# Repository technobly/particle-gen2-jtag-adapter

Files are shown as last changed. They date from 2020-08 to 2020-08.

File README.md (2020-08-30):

Particle Gen2 JTAG/SWD adapter for Gen3 Debugger
===

Allows you to easily connect a Gen3 Particle Debugger to a Gen2 Photon/Electron in circuit using pass-through headers.

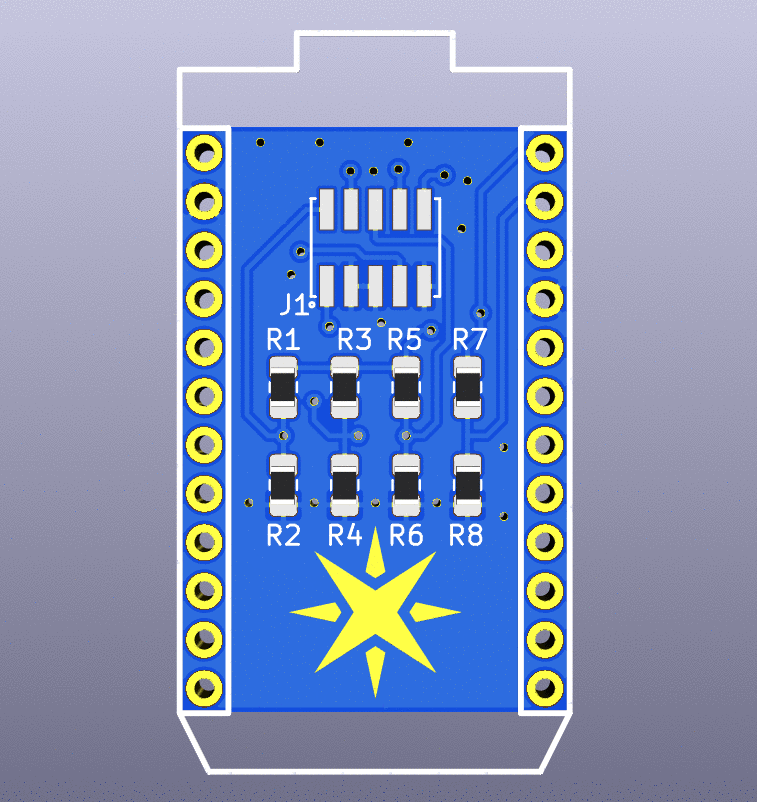
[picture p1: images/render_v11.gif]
render

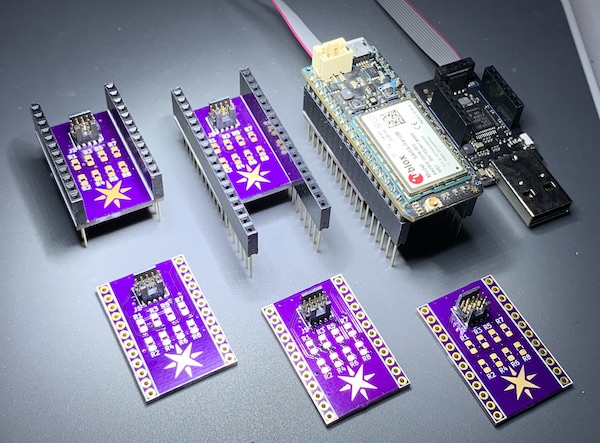
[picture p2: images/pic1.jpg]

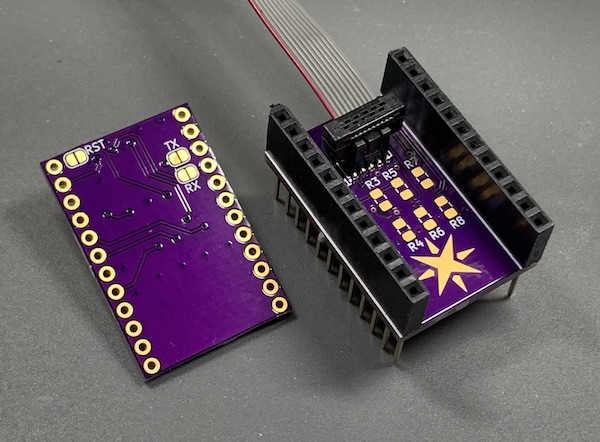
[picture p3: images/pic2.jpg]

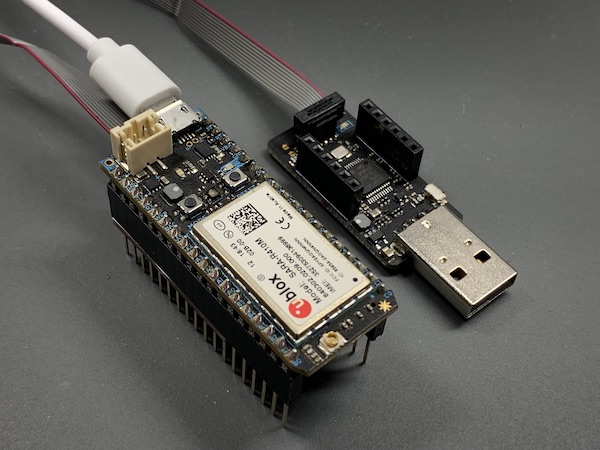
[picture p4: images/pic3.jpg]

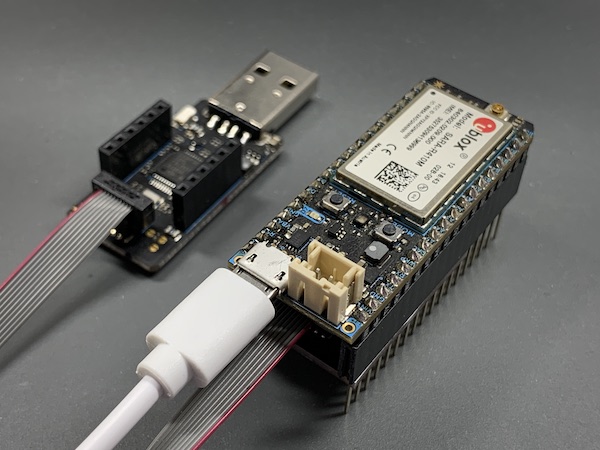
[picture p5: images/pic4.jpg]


BOM
===

- [1x - J1 - FTSH-105-01-F-DV-K](https://www.digikey.com/product-detail/en/samtec-inc/FTSH-105-01-F-DV-K-TR/SAM13160CT-ND/8827915)
- [8x - R1 ~ R8 (Optional, stuff pull up or pull down for each only if desired) - 10K 0805](https://www.digikey.com/product-detail/en/te-connectivity-passive-product/CRGCQ0805F10K/A129761CT-ND/8577593)
- [2x - J2 - 12-pin stackable header](https://www.digikey.com/product-detail/en/sparkfun-electronics/PRT-14322/1568-1651-ND)

LICENSE
===

CERN OHL v2.0 Permissive - essentially do whatever you want, but if you found this useful [please consider buying me a coffee!](https://buymeacoffee.com/XzUGYrhL3)  Full [LICENSE here](LICENSE)

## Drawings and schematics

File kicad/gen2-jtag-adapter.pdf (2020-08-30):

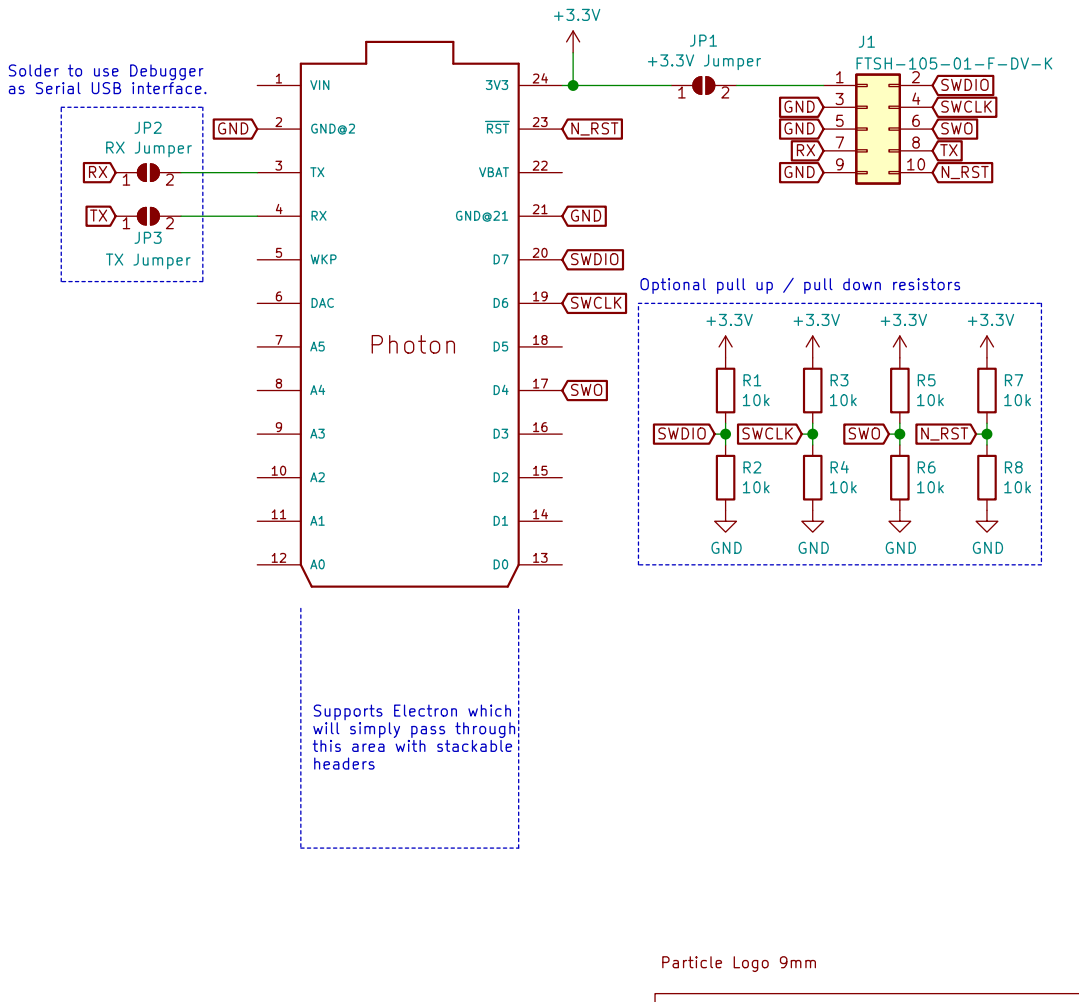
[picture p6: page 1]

File: gen2-jtag-adapter.sch Sheet: / Photon

Supports Electron which
will simply pass through
this area with stackable
headers

Id: 1/1 Title: Particle Gen2 JTAG/SWD Adapter for Gen3 Debugger

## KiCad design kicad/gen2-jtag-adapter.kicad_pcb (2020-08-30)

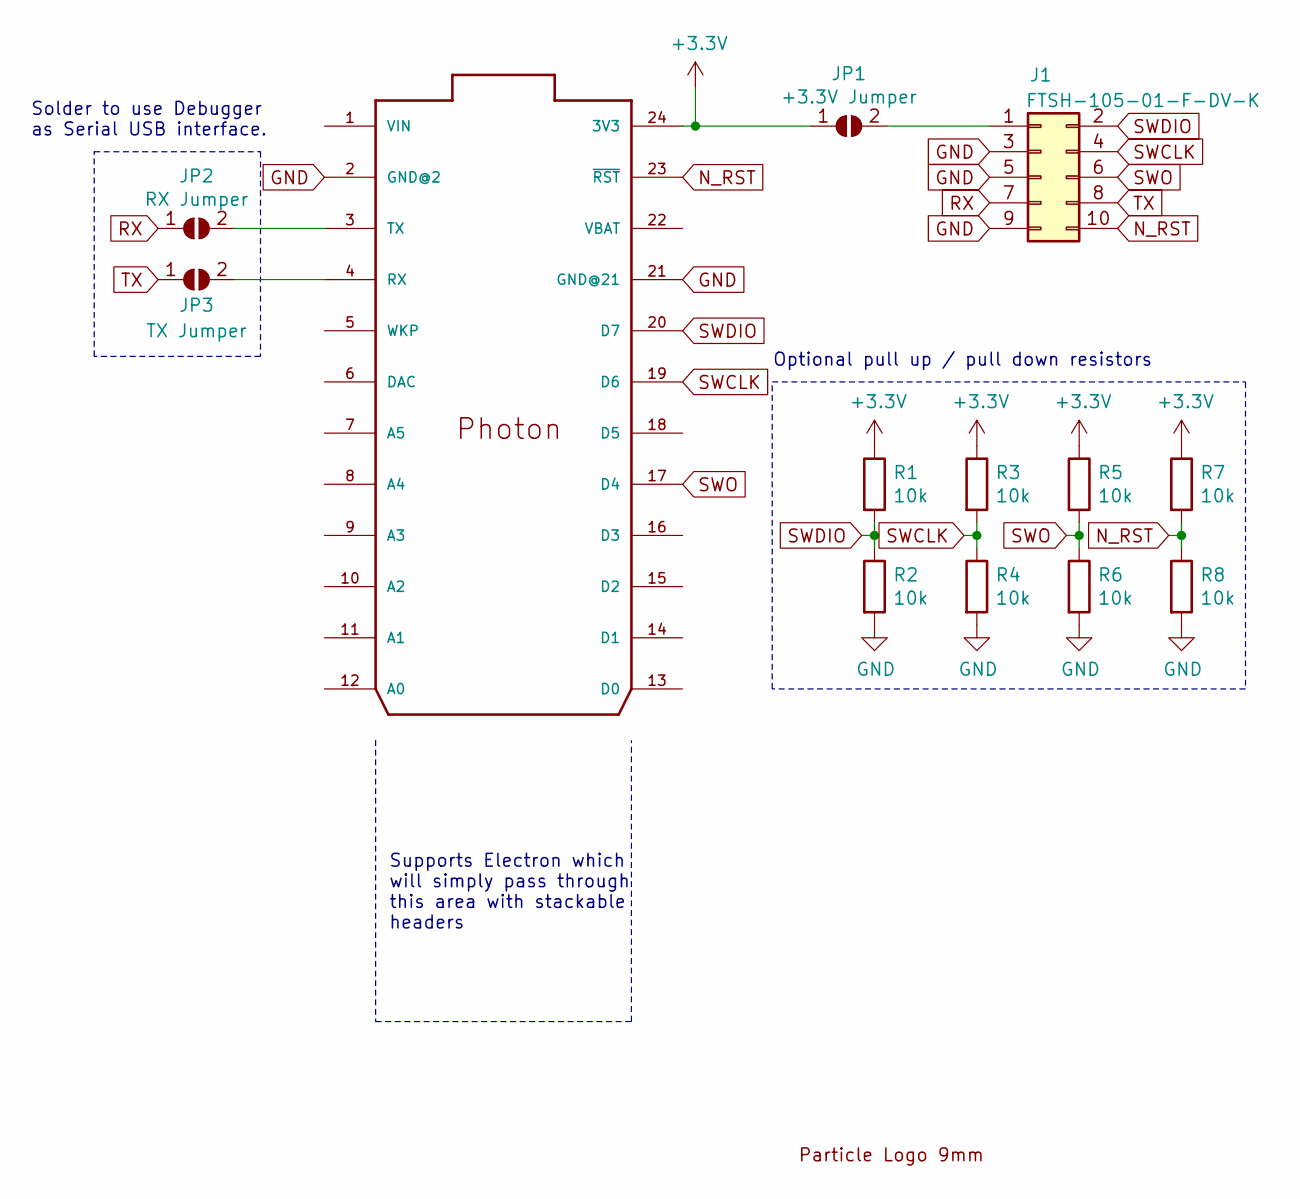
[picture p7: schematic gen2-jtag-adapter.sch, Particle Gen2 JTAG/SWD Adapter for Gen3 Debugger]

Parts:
J1: FTSH-105-01-F-DV-K; CONN5X2_1.27
JP1: +3.3V Jumper; SolderJumper-2_P1.3mm_Open_RoundedPad1.0x1.5mm
JP2: RX Jumper; SolderJumper-2_P1.3mm_Open_RoundedPad1.0x1.5mm
JP3: TX Jumper; SolderJumper-2_P1.3mm_Open_RoundedPad1.0x1.5mm
R1, R2, R3, R4, R5, R6, R7, R8: 10k; R_0805_2012Metric_Pad1.15x1.40mm_HandSolder
U1: PHOTON
U2: PARTICLE_LOGO_9MM; particle-logo-9mm

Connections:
+3V3: JP1.1 (A), R1.1, R3.1, R5.1, R7.1, U1.24 (3V3)
GND: J1.3, J1.5, J1.9, R2.2, R4.2, R6.2, R8.2, U1.2 (GND@2), U1.21 (GND@21)
N_RST: J1.10, R7.2, R8.1, U1.23 (~RST~)
unnamed: J1.1, JP1.2 (B)
unnamed: JP2.2 (B), U1.3 (TX)
unnamed: JP3.2 (B), U1.4 (RX)
RX: J1.7, JP2.1 (A)
SWCLK: J1.4, R3.2, R4.1, U1.19 (D6)
SWDIO: J1.2, R1.2, R2.1, U1.20 (D7)
SWO: J1.6, R5.2, R6.1, U1.17 (D4)
TX: J1.8, JP3.1 (A)

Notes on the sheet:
Solder to use Debugger as Serial USB interface.
Optional pull up / pull down resistors
Supports Electron which will simply pass through this area with stackable headers

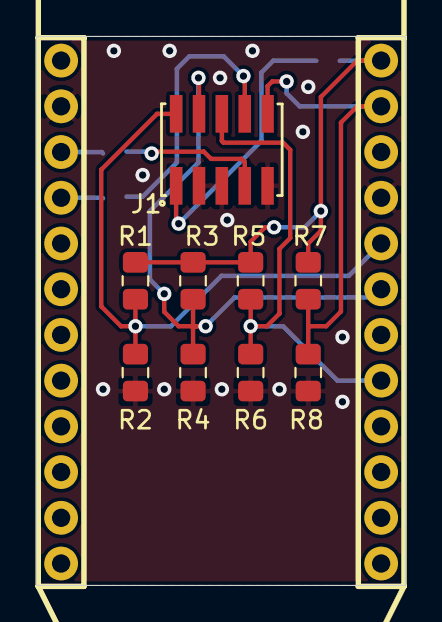
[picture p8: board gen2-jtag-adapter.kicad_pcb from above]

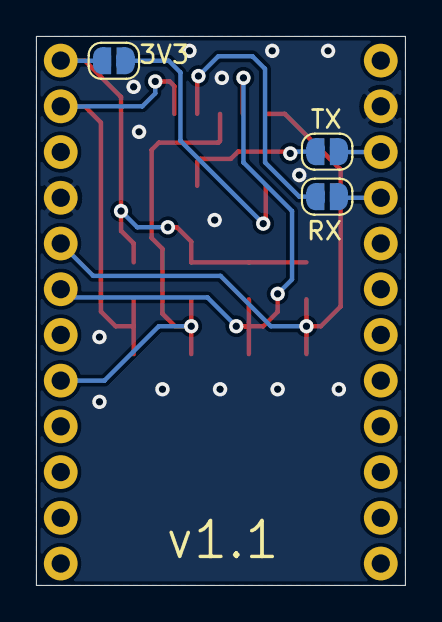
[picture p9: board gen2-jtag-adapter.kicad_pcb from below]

Board: 2 copper layers, 20.5 x 30.5 mm, 14 parts (3 on the bottom side), 11 nets.

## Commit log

2020-08-14 initial release v1.0
    [gen2-jtag-adapter-B_Cu.gbl, gen2-jtag-adapter-B_Mask.gbs, gen2-jtag-adapter-B_Paste.gbp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]
2020-08-15 added BOM
2020-08-30 updated silkscreen, v1.1
    [gen2-jtag-adapter-B_Cu.gbl, gen2-jtag-adapter-B_Mask.gbs, gen2-jtag-adapter-B_Paste.gbp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]
